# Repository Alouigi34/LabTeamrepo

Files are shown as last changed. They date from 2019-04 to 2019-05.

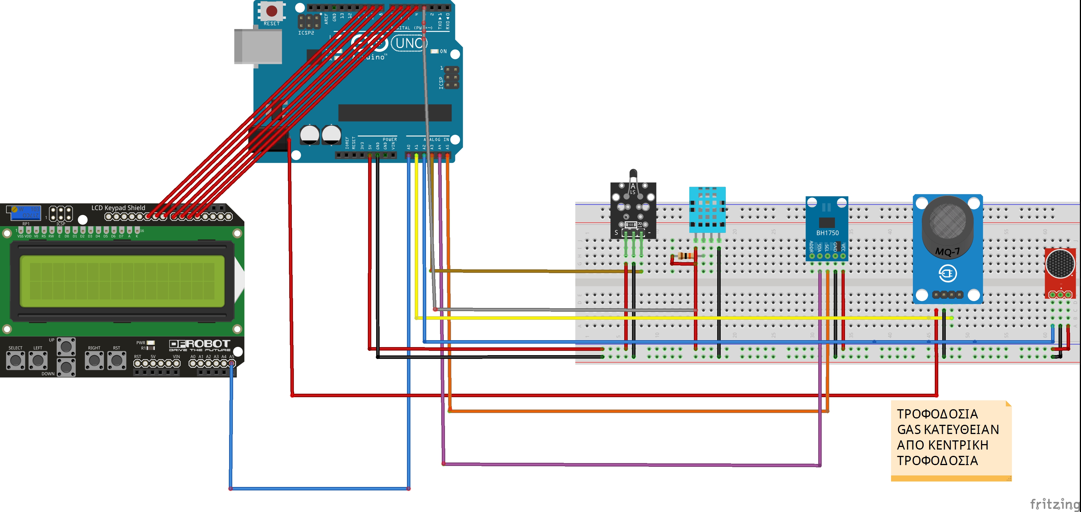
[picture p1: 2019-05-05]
Blueprints/Class_Quality_KYKLOMA_fritzing.jpg

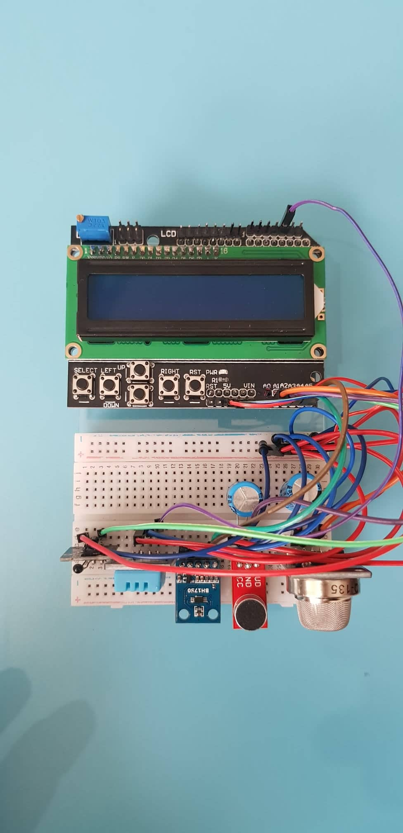
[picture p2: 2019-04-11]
Blueprints/εικονα.jpg

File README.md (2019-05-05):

# LabTeamrepo
Project for arduino competition

Αναλυτική περιγραφή ιδέας 

Η κατασκευή μας έχει σκοπό να μετρήσει την ποιότητα της ζωής μας στην σχολική τάξη. Μετράμε λοιπόν και αξιολογούμε στατιστικά, την θερμοκρασία της τάξης, το θόρυβο των παιδιών, το φως που έχουμε, και την υγρασία του χώρου. Όλες οι μετρήσεις μας συγκρίνονται με τις ιδανικές συνθήκες (παράδειγμα θερμοκρασία 20 βαθμοί και φως 250 λουξ και θόρυβος 35 ντεσιμπέλ) σύμφωνα με τις προδιαγραφές των σχολείων. Ολες οι μετρήσεις συμμετέχουν στο να φτιάξουμε ένα τελικό βαθμό ποιότητας.Το arduino μας  μετρά με τους αισθητήρες, υπολογίζει τον βαθμό και τον δείχνει σε οθόνη μαζί με τις μετρήσεις μία μία.
Στόχος είναι να μπει ένα arduino σε κάθε αίθουσα του σχολείου και να κάνουμε διαγωνισμό για την καλύτερη τάξη. Αυτό θα γίνεται κάθε μέρα και η καλύτερη τάξη στο τέλος του μήνα θα έχει ένα βραβείο από το σχολείο ή από το σύλλογο γονέων του σχολείου.

Χρειαστήκαμε τα παρακάτω υλικά
- 1 arduino UNO
- από έναν αισθητήρα: θερμοκρασίας, ήχου, φωτός, υγρασίας με τις αντιστάσεις τους
- 1 οθόνη 16x2 
- 1 RGB LED
- 1 breadboard και τα καλώδια για να τα ενώσουμε όλα μαζί 

Το συνολικό κόστος της τελικής κατασκευής,είναι περίπου 30 ευρώ

Περιηγηθείτε: 

Στο φάκελο Docs είναι τα αρχεία odt 

Στο φακελο code οι κώδικες

και στον φάκελο Blueprints είναι οι εικόνες και το κύκλωμα που σχεδιάσαμε στο fritzing!

Ο σύνδεσμος μας στο robotics.ellak:

https://robotics.ellak.gr/robotics_participant/metrisi-sinthikon-zois/

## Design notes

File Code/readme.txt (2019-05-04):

Οδηγίες για το arduino IDE
Τοποθετήστε όλα τα αρχεία στον ίδιο φάκελο και ονομάστε τον SCHOOL.
Το main αρχείο είναι το SCHOOL.ino
Να συμπεριλάβετε τις βιβλιοθήκες που βρίσκονται στον φάκελο

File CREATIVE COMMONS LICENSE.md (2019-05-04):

Όλο το υλικό η τεκμηρίωση, ο κώδικας,οι φωτογραφίες μας και όλο το περιεχόμενο του παρόντος site δημιουργήθηκε με open source software: Libre Office, Arduino, Frizzing και το διανέμουμε με άδεια χρήσης Creative Commons CC BY

Creative Commons Attribution-ShareAlike 4.0 International Public License

By exercising the Licensed Rights (defined below), You accept and agree to be bound by the terms and conditions of this Creative Commons Attribution-ShareAlike 4.0 International Public License ("Public License"). To the extent this Public License may be interpreted as a contract, You are granted the Licensed Rights in consideration of Your acceptance of these terms and conditions, and the Licensor grants You such rights in consideration of benefits the Licensor receives from making the Licensed Material available under these terms and conditions.

Section 1 – Definitions.
a.Adapted Material means material subject to Copyright and Similar Rights that is derived from or based upon the Licensed Material and in which the Licensed Material is translated, altered, arranged, transformed, or otherwise modified in a manner requiring permission under the Copyright and Similar Rights held by the Licensor. For purposes of this Public License, where the Licensed Material is a musical work, performance, or sound recording, Adapted Material is always produced where the Licensed Material is synched in timed relation with a moving image.
b.Adapter's License means the license You apply to Your Copyright and Similar Rights in Your contributions to Adapted Material in accordance with the terms and conditions of this Public License.
c.BY-SA Compatible License means a license listed at  creativecommons.org/compatiblelicenses, approved by Creative Commons as essentially the equivalent of this Public License.
d.Copyright and Similar Rights means copyright and/or similar rights closely related to copyright including, without limitation, performance, broadcast, sound recording, and Sui Generis Database Rights, without regard to how the rights are labeled or categorized. For purposes of this Public License, the rights specified in Section 2(b)(1)-(2) are not Copyright and Similar Rights.
e.Effective Technological Measures means those measures that, in the absence of proper authority, may not be circumvented under laws fulfilling obligations under Article 11 of the WIPO Copyright Treaty adopted on December 20, 1996, and/or similar international agreements.
f.Exceptions and Limitations means fair use, fair dealing, and/or any other exception or limitation to Copyright and Similar Rights that applies to Your use of the Licensed Material.
g.License Elements means the license attributes listed in the name of a Creative Commons Public License. The License Elements of this Public License are Attribution and ShareAlike.
h.Licensed Material means the artistic or literary work, database, or other material to which the Licensor applied this Public License.
i.Licensed Rights means the rights granted to You subject to the terms and conditions of this Public License, which are limited to all Copyright and Similar Rights that apply to Your use of the Licensed Material and that the Licensor has authority to license.
j.Licensor means the individual(s) or entity(ies) granting rights under this Public License.
k.Share means to provide material to the public by any means or process that requires permission under the Licensed Rights, such as reproduction, public display, public performance, distribution, dissemination, communication, or importation, and to make material available to the public including in ways that members of the public may access the material from a place and at a time individually chosen by them.
l.Sui Generis Database Rights means rights other than copyright resulting from Directive 96/9/EC of the European Parliament and of the Council of 11 March 1996 on the legal protection of databases, as amended and/or succeeded, as well as other essentially equivalent rights anywhere in the world.
m.You means the individual or entity exercising the Licensed Rights under this Public License. Your has a corresponding meaning.

Section 2 – Scope.
a.License grant. 1.Subject to the terms and conditions of this Public License, the Licensor hereby grants You a worldwide, royalty-free, non-sublicensable, non-exclusive, irrevocable license to exercise the Licensed Rights in the Licensed Material to: A.reproduce and Share the Licensed Material, in whole or in part; and
B.produce, reproduce, and Share Adapted Material.

2.Exceptions and Limitations. For the avoidance of doubt, where Exceptions and Limitations apply to Your use, this Public License does not apply, and You do not need to comply with its terms and conditions.
3.Term. The term of this Public License is specified in Section 6(a).
4.Media and formats; technical modifications allowed. The Licensor authorizes You to exercise the Licensed Rights in all media and formats whether now known or hereafter created, and to make technical modifications necessary to do so. The Licensor waives and/or agrees not to assert any right or authority to forbid You from making technical modifications necessary to exercise the Licensed Rights, including technical modifications necessary to circumvent Effective Technological Measures. For purposes of this Public License, simply making modifications authorized by this Section 2(a)(4) never produces Adapted Material.
5.Downstream recipients. 
A.Offer from the Licensor – Licensed Material. Every recipient of the Licensed Material automatically receives an offer from the Licensor to exercise the Licensed Rights under the terms and conditions of this Public License.
B.Additional offer from the Licensor – Adapted Material. Every recipient of Adapted Material from You automatically receives an offer from the Licensor to exercise the Licensed Rights in the Adapted Material under the conditions of the Adapter’s License You apply.
C.No downstream restrictions. You may not offer or impose any additional or different terms or conditions on, or apply any Effective Technological Measures to, the Licensed Material if doing so restricts exercise of the Licensed Rights by any recipient of the Licensed Material.

6.No endorsement. Nothing in this Public License constitutes or may be construed as permission to assert or imply that You are, or that Your use of the Licensed Material is, connected with, or sponsored, endorsed, or granted official status by, the Licensor or others designated to receive attribution as provided in Section 3(a)(1)(A)(i).

b.Other rights.
1.Moral rights, such as the right of integrity, are not licensed under this Public License, nor are publicity, privacy, and/or other similar personality rights; however, to the extent possible, the Licensor waives and/or agrees not to assert any such rights held by the Licensor to the limited extent necessary to allow You to exercise the Licensed Rights, but not otherwise.
2.Patent and trademark rights are not licensed under this Public License.
3.To the extent possible, the Licensor waives any right to collect royalties from You for the exercise of the Licensed Rights, whether directly or through a collecting society under any voluntary or waivable statutory or compulsory licensing scheme. In all other cases the Licensor expressly reserves any right to collect such royalties.

Section 3 – License Conditions.

Your exercise of the Licensed Rights is expressly made subject to the following conditions.

a.Attribution.

1.If You Share the Licensed Material (including in modified form), You must:
A.retain the following if it is supplied by the Licensor with the Licensed Material: i.identification of the creator(s) of the Licensed Material and any others designated to receive attribution, in any reasonable manner requested by the Licensor (including by pseudonym if designated);
ii.a copyright notice;
iii.a notice that refers to this Public License; 
iv.a notice that refers to the disclaimer of warranties;
v.a URI or hyperlink to the Licensed Material to the extent reasonably practicable;

B.indicate if You modified the Licensed Material and retain an indication of any previous modifications; and
C.indicate the Licensed Material is licensed under this Public License, and include the text of, or the URI or hyperlink to, this Public License.

2.You may satisfy the conditions in Section 3(a)(1) in any reasonable manner based on the medium, means, and context in which You Share the Licensed Material. For example, it may be reasonable to satisfy the conditions by providing a URI or hyperlink to a resource that includes the required information.
3.If requested by the Licensor, You must remove any of the information required by Section 3(a)(1)(A) to the extent reasonably practicable.

b.ShareAlike. 
In addition to the conditions in Section 3(a), if You Share Adapted Material You produce, the following conditions also apply.
1.The Adapter’s License You apply must be a Creative Commons license with the same License Elements, this version or later, or a BY-SA Compatible License.
2.You must include the text of, or the URI or hyperlink to, the Adapter's License You apply. You may satisfy this condition in any reasonable manner based on the medium, means, and context in which You Share Adapted Material.
3.You may not offer or impose any additional or different terms or conditions on, or apply any Effective Technological Measures to, Adapted Material that restrict exercise of the rights granted under the Adapter's License You apply.

Section 4 – Sui Generis Database Rights.

Where the Licensed Rights include Sui Generis Database Rights that apply to Your use of the Licensed Material:
a.for the avoidance of doubt, Section 2(a)(1) grants You the right to extract, reuse, reproduce, and Share all or a substantial portion of the contents of the database;
b.if You include all or a substantial portion of the database contents in a database in which You have Sui Generis Database Rights, then the database in which You have Sui Generis Database Rights (but not its individual contents) is Adapted Material, including for purposes of Section 3(b); and
c.You must comply with the conditions in Section 3(a) if You Share all or a substantial portion of the contents of the database.
For the avoidance of doubt, this Section 4 supplements and does not replace Your obligations under this Public License where the Licensed Rights include other Copyright and Similar Rights. 
Section 5 – Disclaimer of Warranties and Limitation of Liability.
a.Unless otherwise separately undertaken by the Licensor, to the extent possible, the Licensor offers the Licensed Material as-is and as-available, and makes no representations or warranties of any kind concerning the Licensed Material, whether express, implied, statutory, or other. This includes, without limitation, warranties of title, merchantability, fitness for a particular purpose, non-infringement, absence of latent or other defects, accuracy, or the presence or absence of errors, whether or not known or discoverable. Where disclaimers of warranties are not allowed in full or in part, this disclaimer may not apply to You.
b.To the extent possible, in no event will the Licensor be liable to You on any legal theory (including, without limitation, negligence) or otherwise for any direct, special, indirect, incidental, consequential, punitive, exemplary, or other losses, costs, expenses, or damages arising out of this Public License or use of the Licensed Material, even if the Licensor has been advised of the possibility of such losses, costs, expenses, or damages. Where a limitation of liability is not allowed in full or in part, this limitation may not apply to You.
c.The disclaimer of warranties and limitation of liability provided above shall be interpreted in a manner that, to the extent possible, most closely approximates an absolute disclaimer and waiver of all liability.

Section 6 – Term and Termination.
a.This Public License applies for the term of the Copyright and Similar Rights licensed here. However, if You fail to comply with this Public License, then Your rights under this Public License terminate automatically.

b.Where Your right to use the Licensed Material has terminated under Section 6(a), it reinstates:
1.automatically as of the date the violation is cured, provided it is cured within 30 days of Your discovery of the violation; or
2.upon express reinstatement by the Licensor.
For the avoidance of doubt, this Section 6(b) does not affect any right the Licensor may have to seek remedies for Your violations of this Public License.
c.For the avoidance of doubt, the Licensor may also offer the Licensed Material under separate terms or conditions or stop distributing the Licensed Material at any time; however, doing so will not terminate this Public License.
d.Sections 1, 5, 6, 7, and 8 survive termination of this Public License.

Section 7 – Other Terms and Conditions.
a.The Licensor shall not be bound by any additional or different terms or conditions communicated by You unless expressly agreed.
b.Any arrangements, understandings, or agreements regarding the Licensed Material not stated herein are separate from and independent of the terms and conditions of this Public License.

Section 8 – Interpretation.
a.For the avoidance of doubt, this Public License does not, and shall not be interpreted to, reduce, limit, restrict, or impose conditions on any use of the Licensed Material that could lawfully be made without permission under this Public License.
b.To the extent possible, if any provision of this Public License is deemed unenforceable, it shall be automatically reformed to the minimum extent necessary to make it enforceable. If the provision cannot be reformed, it shall be severed from this Public License without affecting the enforceability of the remaining terms and conditions.
c.No term or condition of this Public License will be waived and no failure to comply consented to unless expressly agreed to by the Licensor.
d.Nothing in this Public License constitutes or may be interpreted as a limitation upon, or waiver of, any privileges and immunities that apply to the Licensor or You, including from the legal processes of any jurisdiction or authority.

Creative Commons is not a party to its public licenses. Notwithstanding, Creative Commons may elect to apply one of its public licenses to material it publishes and in those instances will be considered the “Licensor.” The text of the Creative Commons public licenses is dedicated to the public domain under the CC0 Public Domain Dedication. Except for the limited purpose of indicating that material is shared under a Creative Commons public license or as otherwise permitted by the Creative Commons policies published at creativecommons.org/policies, Creative Commons does not authorize the use of the trademark “Creative Commons” or any other trademark or logo of Creative Commons without its prior written consent including, without limitation, in connection with any unauthorized modifications to any of its public licenses or any other arrangements, understandings, or agreements concerning use of licensed material. For the avoidance of doubt, this paragraph does not form part of the public licenses.

 Creative Commons may be contacted at creativecommons.org.

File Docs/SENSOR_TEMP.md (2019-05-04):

Ky-013 (Analog Temperature Sensor)

1.1Περιληπτική εισαγωγή:
Σκοπός του Analog Temperature Sensor (Analog Temp) είναι να υπολογίζει με ακρίβεια την θερμοκρασία μίας σχολικής τάξης, χρησιμοποιώντας μετρήσεις. Αυτές τις μετρήσεις στη συνέχεια με τη βοήθεια μαθηματικών πράξεων τις μετατρέπουμε στην τελική τους μορφή (θερμοκρασία).

1.2Βουτιά στα καλώδια:
Ο Analog Temp αποτελείται από δύο αντιστάσεις, μια μεταβλητή και μια σταθερή αντίσταση και λειτουργεί με την ίδια νοοτροπία μίας μεταβλητής αντίστασης.  Όσο η θερμοκρασία του δωματίου αυξάνεται, τόσο μειώνεται η τάση η οποία μεταφέρεται από τον αισθητήρα στον εγκέφαλο (arduino) . Έτσι, οι μετρήσεις που λαμβάνει το Arduino σε συνδυασμό με μια μικρή σειρά μαθηματικών πράξεων, μας επιτρέπουν να υπολογίσουμε την θερμοκρασία ενός χώρου 25 περίπου τετραγωνικών μέτρων.      

(συνδεσμολογία-εικόνα στο αντίστοιχο odt)

1.3 Η τελική τιμή:
Καθώς η θερμοκρασία η οποία μας δίνεται από τον αισθητήρα είναι σε Fahrenheit(F), είναι απαραίτητη μια μετατροπή, έτσι ώστε οι τιμές που λαμβάνουμε να είναι σε Celsius(C).
Στη συνέχεια με ένα πρόγραμμα optimization δικής μας κατασκευής, δημιουργούμε ένα τελικό σκορ, το οποίο μαζί με τις επιδόσεις των άλλων αισθητήρων μας δίνουν την τελική βαθμολογία!
Στον κώδικα φαίνονται περισσότερα με σχόλια και παρατηρήσεις.

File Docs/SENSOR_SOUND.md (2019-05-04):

SOUND SENSOR

Προκειμένου να καταλάβουμε το επίπεδο του θορύβου που υπάρχει μέσα σε μία τάξη χρησιμοποιούμε τον sound sensor. Αλλά πώς μπορούμε να μετρήσουμε το ήχο με το Arduino; Αυτό για να το εξηγήσουμε πρέπει πρώτα να δούμε την έξοδο του αισθητήρα και το επιτυγχάνουμε μέσω των  παρακάτω γραφημάτων.
(δείτε odt)
Καταρχάς ένα απλό ηχείο για να δημιουργήσει ήχο ταλαντώνει μια λεπτή πλαστική μεμβράνη η οποία από τις πολλές και συνεχόμενες ταλαντώσεις παράγει ήχο. Αυτή η ταλάντωση παρουσιάζεται ως γράφημα που μας δείχνει την ένταση του ήχου σε συνάρτηση με τον χρόνο (κόκκινο χρώμα). Όταν υπάρχει ησυχία μέσα στην τάξη τότε η κόκκινη γραμμή θα έχει πολύ μικρή διαφορά με την κίτρινη, η οποία εκφράζει την απόλυτη ησυχία (500).
(δείτε odt)
	Στο πρόγραμμα για να καταλάβουμε την μέση ένταση, αφαιρούμε σε κάθε δείγμα που παίρνουμε, την απόσταση του δείγματος από την αμετάβλητη τιμή για να βρούμε την διαφορά. Μετά από 100 μετρήσεις αθροίζουμε τις αποστάσεις  και τις διαιρούμε με το σύνολο των μετρήσεων. Έτσι βρίσκουμε τον μέσο όρο των αποστάσεων.
	Όπως βλέπουμε στο δεύτερο σχήμα επειδή σε αυτό υπάρχει μικρή απόσταση των σημείων από την αμετάβλητη τιμή (την κίτρινη γραμμή)  μέσα στην τάξη υπάρχει ησυχία, άρα συμπεραίνουμε ότι ο θόρυβος μέσα στην τάξη είναι ιδανικός.
	Η ένταση του ήχου μέσα στην τάξη μπορεί να μεταβληθεί πολύ γρήγορα (από ένα φτέρνισμα μέχρι και μια βροντή που μπορεί να ακουστεί από έξω από την τάξη). Για αυτό και εμείς παίρνουμε πολύ περισσότερες τιμές από τον sound sensor σε σχέση με τους υπολοίπους αισθητήρες που χρησιμοποιούμε. Για την ακρίβεια παίρνουμε 100 τιμές ανά 10 δευτερόλεπτα στον sound sensor ενώ στους υπόλοιπους sensors παίρνουμε 1 τιμή ανά 10 δευτερόλεπτα, γιατί οι άλλες τιμές οι οποίες μετράμε μεταβάλλονται πολύ πιο δύσκολα σε σχέση με τον ήχο μέσα σε μια τάξη.
Στον κώδικα έχουμε αναλυτικά και με  σχόλια τι κάνουμε.

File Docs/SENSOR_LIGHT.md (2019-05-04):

ΑΙΣΘΗΤΗΡΑΣ LIGHT
ΕΙΣΑΓΩΓΗ-ΠΕΡΙΛΗΨΗ

Η τάξη πρέπει να έχει 250 lux. O σκοπός του light sensor είναι να ξέρουμε τι φωτεινότητα έχει η τάξη
και ανάλογα με το φως να βάζουμε μία βαθμολογία για την ποιότητα του φωτός όλης της ημέρας.
 
ΑΞΙΟΠΟΙΗΣΗ ΜΕΤΡΟΥΜΕΝΗΣ ΤΙΜΗΣ ΑΠΟ ΤΟ ARDUINO

Διαβάζοντας τις τιμές από τον αισθητήρα παρατηρήσαμε ότι οι μετρούμενες τιμές δεν ήταν σε lux. Τα κινητά μας είχαν αισθητήρες φωτός και τα χρησιμοποιήσαμε ως όργανα μέτρησης. Χρησιμοποιώντας ένα φακό φωτίζαμε συγχρόνως και τους δύο αισθητήρες (του κινητού και τον δικό μας). Ο αισθητήρας του κινητού ήταν η αναφορά μας. Τους φωτίσαμε από πολλά διαφορετικά ύψη και με το LibreOffice Calc φτιάξαμε έναν πίνακα δύο στηλών. Η πρώτη στήλη ήταν οι μετρήσεις του κινητού ενώ η δεύτερη στήλη ήταν οι μετρήσεις του αισθητήρα μας.

Βρήκαμε έναν τύπο που συνδέει τις μετρήσεις του κινητού με τις μετρήσεις του αισθητήρα. Και τον χρησιμοποιήσαμε μέσα στον κώδικα για να μετατρέπουμε τις τιμές που διαβάζουμε από το arduino σε lux.

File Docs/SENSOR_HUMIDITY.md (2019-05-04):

ΑΙΣΘΗΤΗΡΑΣ υγρασίας

Χρησιμοποιούμε τον αισθητήρα θερμοκρασίας και υγρασίας  DHT11  γιατί ήταν ο πιο φθηνός και επειδή καθιστά πραγματικά εύκολη την προσθήκη δεδομένων υγρασίας και θερμοκρασίας.

ΑΞΙΟΠΟΙΗΣΗ ΜΕΤΡΟΥΜΕΝΗΣ ΤΙΜΗΣ ΑΠΟ ΤΟ ARDUINO
Η κατάλληλη υγρασία είναι περίπου 50% όλες τις εποχές. Τα όρια που χρησιμοποιήσαμε είναι τα εξής: {0, 15, 55,80, 100}

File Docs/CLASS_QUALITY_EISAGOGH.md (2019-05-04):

CQM0419 – Class Quality Monitor  - Απρίλιος 2019

Δημιουργία συσκευής που μετρά την ποιότητα της τάξης

Η καθημερινή μας ζωή στην σχολική τάξη μπορεί να βελτιωθεί αν οι περιβαλλοντικές συνθήκες είναι όσο δυνατόν καλύτερες. Όταν κάτι δεν μας αρέσει πρέπει να βρούμε εύκολα τι είναι αυτό που μας προκαλεί δυσφορία.  

Αποφασίσαμε να φτιάξουμε μία κατασκευή που θα μπορεί να μετρά την ποιότητα ζωής στην τάξη με σκοπό να την βελτιώσει. Βασικοί παράγοντες που επηρεάζουν τη ζωή στην τάξη, είναι οι συνθήκες θερμοκρασίας, υγρασίας, θορύβου, φωτός και ποιότητας αέρα. Η κατασκευή μας είναι οι αισθητήρες αυτοί όλοι μαζί σε ένα arduino, μία lcd μικρή οθόνη που θα δείχνει τα αναλυτικά αποτελέσματα και ένα led που θα ανάβει πράσινο, κίτρινο ή κόκκινο αν η τάξη συνολικά είναι άριστη, μέτρια ή κακή.

Η ομάδα μας έχει μαθητές από Πέμπτη Δημοτικού μέχρι Τρίτη Γυμνασίου και προκειμένου να επιτύχουμε τον στόχο μας, δημιουργήσαμε μία υπο-ομάδα για κάθε αισθητήρα χωριστά και μία ομάδα για το τελικό integration. Αφότου κάθε ομάδα ολοκλήρωσε τη δουλειά της, χωριστήκαμε εκ νέου σε νέες ομάδες προκειμένου σχεδιάσουμε το κύκλωμα σε fritzing, να γράψουμε τα documents, να κάνουμε αποσφαλμάτωση στους κώδικες και να βελτιώσουμε τον κώδικα και το hardware.
Η όλη φιλοσοφία της κατασκευής είναι να παίρνουμε μετρήσεις από κάθε αισθητήρα και ανά τακτά διαστήματα να τις αξιολογούμε καθεμία και όλες μαζί.

Αντιμετωπίσαμε πολλά προβλήματα. Προβλήματα συνεννόησης, χρόνου, οργάνωσης συναντήσεων, προβλήματα με το software αλλά και το hardware. Οι κώδικες χρήσης αισθητήρων, που βρήκαμε από το internet, δε δούλευαν πάντα σωστά και έπρεπε να τους κάνουμε κάποιες μετατροπές. Έπειτα, μας δυσκόλεψε πολύ η ενοποίηση των επιμέρους προγραμμάτων σε ένα τελικό. Στο hardware, έπρεπε να είμαστε πολύ προσεκτικοί με την θέση των αισθητήρων και επιλογή των pins γιατί είχαμε πολλούς αισθητήρες και μία lcd οθόνη που έπιαναν πολλά pins. Ήταν πολύ σημαντική η σωστή διάταξη των αισθητήρων πάνω στο breadboard διότι για παράδειγμα αν ο gas sensor που ζεσταινότανε πολύ, κατά τη διάρκεια της λειτουργίας του, ήταν δίπλα στον temperature sensor το αποτέλεσμα θα ήταν λανθασμένο. Θέλει πολύ προσοχή η σωστή χρήση της συσκευής. Για παράδειγμα δεν πρέπει να σκύβουμε από πάνω γιατί ο light sensor θα βγάλει λάθος μετρήσεις. Να επισημάνουμε μια ιδιαιτερότητα που είχε ο gas sensor, ότι η τροφοδοσία του δεν έπρεπε να γίνεται μέσο της τροφοδοσίας του arduino, αλλά μέσο της USB τροφοδοσίας. Διαφορετικά, επειδή ο gas sensor καταναλώνει πολύ ρεύμα, η lcd οθόνη τρεμοπαίζει και γενικά όλο το κύκλωμα είναι ασταθές.

Χαιρόμαστε γιατί μάθαμε πολλά πράγματα. Είδαμε πόσο ωραίο είναι να δουλεύεις σε ομάδες, με όλες τις δυσκολίες μας. Μάθαμε με τη βοήθεια του δασκάλου μας να φτιάχνουμε καλύτερο και παραμετρικό κώδικα (ειδικά με το integration) και πόσο πραγματικά βολεύει να σχεδιάζουμε τα πάντα στο χαρτί (κύκλωμα και κώδικα) πριν τα υλοποιήσουμε.
Τώρα έχουμε μια πλήρη κατασκευή που σε 5 λεπτά αλλάζουμε ότι θέλουμε (καλύτερους αισθητήρες, παραμέτρους ελέγχους ποιότητας μετρήσεων) και θα θέλαμε να την δούμε ζωντανά  να δουλεύει σε πραγματική λειτουργία σε κάθε τάξη στα σχολεία μας.

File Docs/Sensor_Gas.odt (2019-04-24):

Air Quality

1.1

Ο Air Quality MQ-135 είναι ένας αισθητήρας που μετράει την ποιότητα του αέρα. Για παράδειγμα μετράει το CO2 (το διοξείδιο του άνθρακα), την αλκοόλη ,τον καπνό , το NH3(αμμωνία) κτλ. Χρησιμοποιείται ως δείκτης ποιότητας του αέρα AQI (Air Quality index) . Για το πόσο μολυσμένος είναι ο αέρας σήμερα ή πόσο μολυσμένος προβλέπεται να γίνει. Καθώς αυξάνεται το AQI (Air Quality index), μεγάλο ποσοστό του πληθυσμού είναι πιθανό να εμφανίσει όλο και πιο σοβαρές επιπτώσεις στην υγεία του. Οι διάφορες χώρες έχουν τους δικούς τους δείκτες ποιότητας του αέρα, οι οποίοι αντιστοιχούν σε διαφορετικά εθνικά πρότυπα. Μερικά από αυτά είναι ο Δείκτης Υγείας Ποιότητας Αέρα (Καναδάς), ο Δείκτης Αέριας Ρύπανσης (Μαλαισία) και ο Δείκτης Πρότυπων Ρύπων (Σιγκαπούρη). Η ποιότητα του αέρα της τάξης είναι πολύ σημαντική για να μην αρρωσταίνουν ευκολά τα παιδιά και για να μπορούν να παρακολουθήσουν καλύτερα στο μάθημα .Συγκεκριμένα οι τιμές του CO2(διοξείδιού του άνθρακα ) πρέπει να είναι <1000ppm σύμφωνα με τα διεθνή στάνταρ.

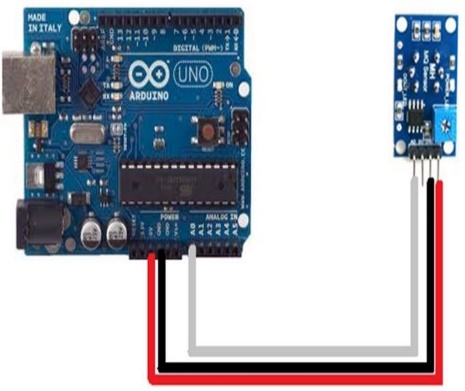
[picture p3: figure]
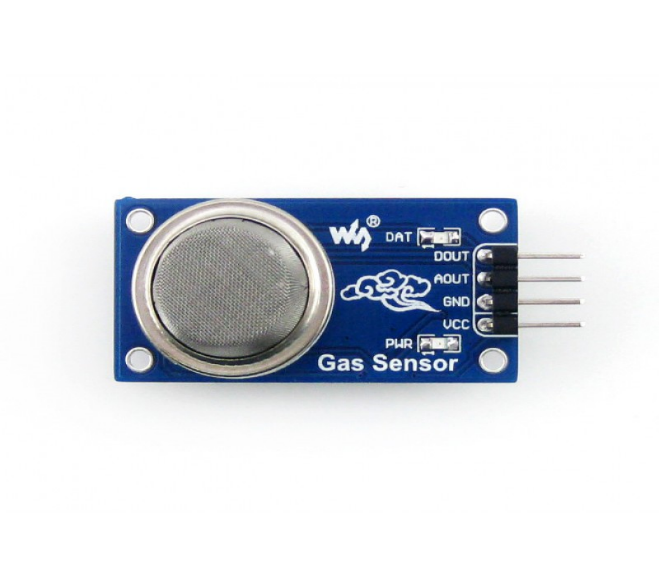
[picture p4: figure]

1.2

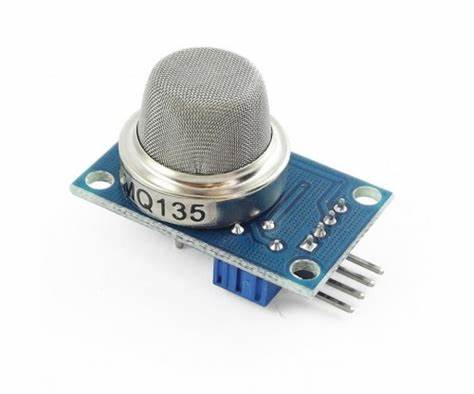
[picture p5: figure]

Ι) στην εικόνα αυτή βλέπουμε τον sensor MQ-135 VCC=5v

GND=GND

ADUT=8

DDUT=9

1.3

Οι αποδεκτές τιμές είναι κάτω από 1000ppm . Ο sensor MQ-135 δεν χρειάζεται μετατροπή γιατί μετράει σε ppm .

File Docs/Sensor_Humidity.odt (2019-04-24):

# 1.ΑΙΣΘΗΤΗΡΑΣ υγρασίας

## 1.1.ΕΙΣΑΓΩΓΗ-ΠΕΡΙΛΗΨΗ

Σε αυτή την ενότητα θα επικεντρωθούμε στον αισθητήρα υγρασίας.

Χρησιμοποιούμε τον αισθητήρα θερμοκρασίας και υγρασίας DHT11 γιατί ήταν ο πιο φθηνός και επειδή καθιστά πραγματικά εύκολη την προσθήκη δεδομένων υγρασίας και θερμοκρασίας.
1.2.Ο ΑΙΣΘΗΤΗΡΑΣ ΜΑΣ

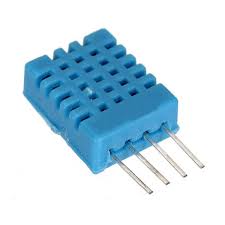
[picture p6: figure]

Εικόνα 1 :O αισθητήρας DHT_11

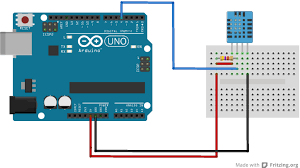
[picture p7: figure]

Εικόνα 2:H συνδεσμολογία του DHT_11 με το arduino.

## 1.3.ΑΞΙΟΠΟΙΗΣΗ ΜΕΤΡΟΥΜΕΝΗΣ ΤΙΜΗΣ ΑΠΟ ΤΟ ARDUINO

Η κατάλληλη υγρασία είναι περίπου 50% όλες τις εποχές. Τα όρια που χρησιμοποιήσαμε αρχικά είναι τα εξής: {0, 15, 55,80, 100}

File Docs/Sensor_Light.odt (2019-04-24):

# 1.ΑΙΣΘΗΤΗΡΑΣ LIGHT

## 1.1.ΕΙΣΑΓΩΓΗ-ΠΕΡΙΛΗΨΗ

Η τάξη πρέπει να έχει 250 lux. O σκοπός του light sensor είναι να ξέρουμε τι φωτεινότητα έχει η τάξη

και ανάλογα με το φως να βάζουμε μία βαθμολογία για την ποιότητα του φωτός όλης της ημέρας.

## 1.2.Ο ΑΙΣΘΗΤΗΡΑΣ ΜΑΣ

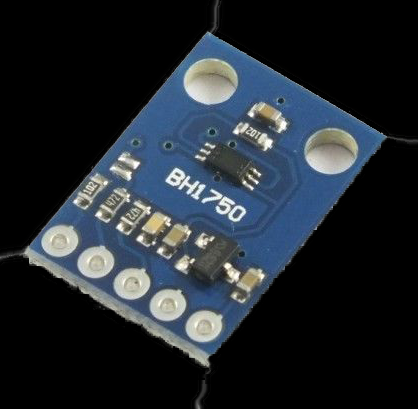
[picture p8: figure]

Εικόνα 1: Εικόνα του αισθητήρα

## 1.3.ΑΞΙΟΠΟΙΗΣΗ ΜΕΤΡΟΥΜΕΝΗΣ ΤΙΜΗΣ ΑΠΟ ΤΟ ARDUINO

Διαβάζοντας τις τιμές από τον αισθητήρα παρατηρήσαμε ότι οι μετρούμενες τιμές δεν ήταν σε lux. Τα κινητά μας είχαν αισθητήρες φωτός και τα χρησιμοποιήσαμε ως όργανα μέτρησης. Χρησιμοποιώντας ένα φακό φωτίζαμε συγχρόνως και τους δύο αισθητήρες (του κινητού και τον δικό μας). Ο αισθητήρας του κινητού ήταν η αναφορά μας. Τους φωτίσαμε από πολλά διαφορετικά ύψη και με το LibreOffice Calc φτιάξαμε έναν πίνακα δύο στηλών. Η πρώτη στήλη ήταν οι μετρήσεις του κινητού ενώ η δεύτερη στήλη ήταν οι μετρήσεις του αισθητήρα μας.

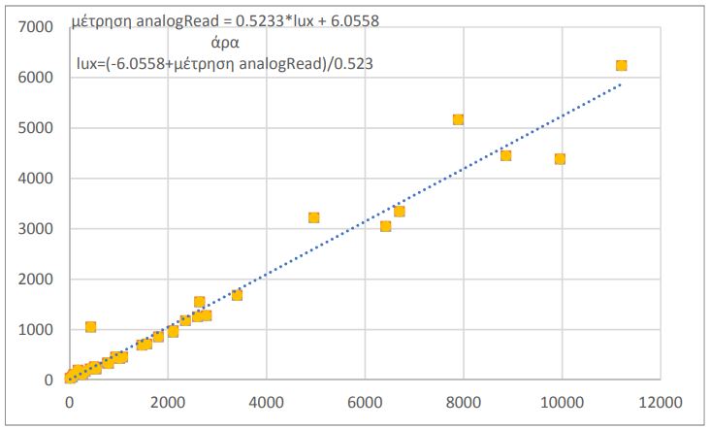
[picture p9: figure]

ΕΙΚΟΝΑ 1: Kάθετος άξονας: μετρήσεις κινητού. Oριζόντιος άξονας: Mετρήσεις arduino.

Βρήκαμε έναν τύπο που συνδέει τις μετρήσεις του κινητού με τις μετρήσεις του αισθητήρα. Και τον χρησιμοποιήσαμε μέσα στον κώδικα για να μετατρέπουμε τις τιμές που διαβάζουμε από το arduino σε lux.

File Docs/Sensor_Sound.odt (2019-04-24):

SOUND SENSOR

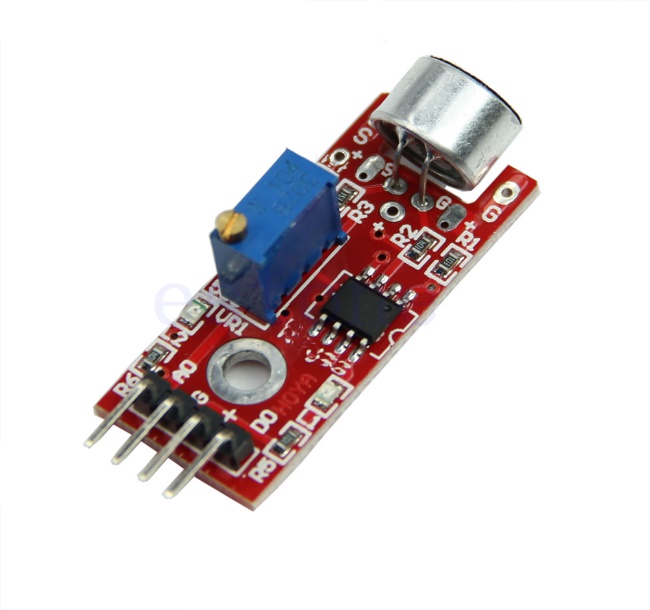
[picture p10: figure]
Εμφάνιση της εικόνας προέλευσης
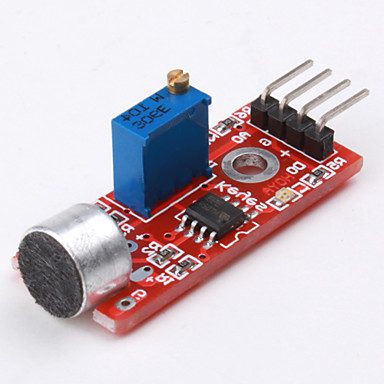
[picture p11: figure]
Εμφάνιση της εικόνας προέλευσης

Προκειμένου να καταλάβουμε το επίπεδο του θορύβου που υπάρχει μέσα σε μία τάξη χρησιμοποιούμε τον sound sensor. Αλλά πώς μπορούμε να μετρήσουμε το ήχο με το Arduino; Αυτό για να το εξηγήσουμε πρέπει πρώτα να δούμε την έξοδο του αισθητήρα και το επιτυγχάνουμε μέσω των παρακάτω γραφημάτων.

Εικόνα 1: Η έξοδος του αισθητήρα στην ησυχία (-->κίτρινη γραμμή: η απόλυτη ησυχία--> κόκινη γραμμή: έξοδος αισθητήρα )

Εικόνα 2: Η έξοδος του αισθητήρα στην φασαρία (-->κίτρινη γραμμή: η απόλυτη ησυχία--> κόκινη γραμμή: έξοδος αισθητήρα )

Καταρχάς ένα απλό ηχείο για να δημιουργήσει ήχο ταλαντώνει μια λεπτή πλαστική μεμβράνη η οποία από τις πολλές και συνεχόμενες ταλαντώσεις παράγει ήχο. Αυτή η ταλάντωση παρουσιάζεται ως γράφημα που μας δείχνει την ένταση του ήχου σε συνάρτηση με τον χρόνο (κόκκινο χρώμα). Όταν υπάρχει ησυχία μέσα στην τάξη τότε η κόκκινη γραμμή θα έχει πολύ μικρή διαφορά με την κίτρινη, η οποία εκφράζει την απόλυτη ησυχία (500).

Στο πρόγραμμα για να καταλάβουμε την μέση ένταση, αφαιρούμε σε κάθε δείγμα που παίρνουμε, την απόσταση του δείγματος από την αμετάβλητη τιμή για να βρούμε την διαφορά. Μετά από 100 μετρήσεις αθροίζουμε τις αποστάσεις και τις διαιρούμε με το σύνολο των μετρήσεων. Έτσι βρίσκουμε τον μέσο όρο των αποστάσεων.

Όπως βλέπουμε στο δεύτερο σχήμα επειδή σε αυτό υπάρχει μικρή απόσταση των σημείων από την αμετάβλητη τιμή (την κίτρινη γραμμή) μέσα στην τάξη υπάρχει ησυχία, άρα συμπεραίνουμε ότι ο θόρυβος μέσα στην τάξη είναι ιδανικός.

Η ένταση του ήχου μέσα στην τάξη μπορεί να μεταβληθεί πολύ γρήγορα (από ένα φτέρνισμα μέχρι και μια βροντή που μπορεί να ακουστεί από έξω από την τάξη). Για αυτό και εμείς παίρνουμε πολύ περισσότερες τιμές από τον sound sensor σε σχέση με τους υπολοίπους αισθητήρες που χρησιμοποιούμε. Για την ακρίβεια παίρνουμε 100 τιμές ανά 10 δευτερόλεπτα στον sound sensor ενώ στους υπόλοιπους sensors παίρνουμε 1 τιμή ανά 10 δευτερόλεπτα, γιατί οι άλλες τιμές οι οποίες μετράμε μεταβάλλονται πολύ πιο δύσκολα σε σχέση με τον ήχο μέσα σε μια τάξη.

Στον κώδικα έχουμε αναλυτικά και με σχόλια τι κάνουμε.

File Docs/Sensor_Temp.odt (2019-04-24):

Ky-013 (Analog Temperature Sensor)

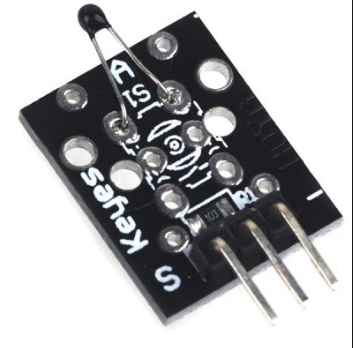
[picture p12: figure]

1.1Περιληπτική εισαγωγή:

Σκοπός του Analog Temperature Sensor (Analog Temp) είναι να υπολογίζει με ακρίβεια την θερμοκρασία μίας σχολικής τάξης, χρησιμοποιώντας μετρήσεις. Αυτές τις μετρήσεις στη συνέχεια με τη βοήθεια μαθηματικών πράξεων τις μετατρέπουμε στην τελική τους μορφή (θερμοκρασία).

1.2Βουτιά στα καλώδια:

Ο Analog Temp αποτελείται από δύο αντιστάσεις, μια μεταβλητή και μια σταθερή αντίσταση και λειτουργεί με την ίδια νοοτροπία μίας μεταβλητής αντίστασης. Όσο η θερμοκρασία του δωματίου αυξάνεται, τόσο μειώνεται η τάση η οποία μεταφέρεται από τον αισθητήρα στον εγκέφαλο (arduino) . Έτσι, οι μετρήσεις που λαμβάνει το Arduino σε συνδυασμό με μια μικρή σειρά μαθηματικών πράξεων, μας επιτρέπουν να υπολογίσουμε την θερμοκρασία ενός χώρου 25 περίπου τετραγωνικών μέτρων.

Η παρακάτω εικόνα απεικονίζει τη συνδεσμολογία του αισθητήρα

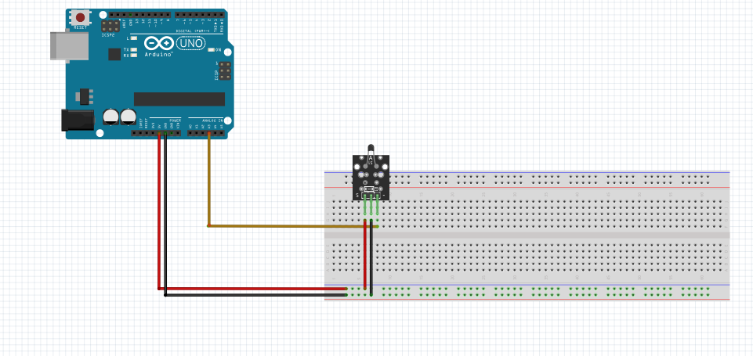
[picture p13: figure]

Το καφέ καλώδιο συνδέεται με το Pin A3 και με ένα “πόδι” του αισθητήρα, έτσι ώστε να μεταφέρονται οι μετρήσεις του.

Τα άλλα δυο καλώδια έχουν σχέση με την παροχή ενέργειας του (5 volt και γείωση).

1.3 Η τελική τιμή:

Καθώς η θερμοκρασία η οποία μας δίνεται από τον αισθητήρα είναι σε Fahrenheit(F), είναι απαραίτητη μια μετατροπή, έτσι ώστε οι τιμές που λαμβάνουμε να είναι σε Celsius(C).

Στη συνέχεια με ένα πρόγραμμα optimization δικής μας κατασκευής, δημιουργούμε ένα τελικό σκορ, το οποίο μαζί με τις επιδόσεις των άλλων αισθητήρων μας δίνουν την τελική βαθμολογία!

Στον κώδικα φαίνονται περισσότερα με σχόλια και παρατηρήσεις.

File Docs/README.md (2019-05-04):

Εδώ περιγράφουμε αναλυτικά τη κατασκευή μας.
Προτιμήστε τα odt αρχεία γιατί περιέχουν εικόνες και σχήματα που βοηθούν στην κατανόηση.

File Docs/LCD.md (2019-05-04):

LCD Screen

Στην οθόνη, ανάλογα με το κουμπί που πατάμε, εκτυπώνουμε τον πίνακα κατανομής που αντιστοιχεί στον αισθητήρα που επιλέγουμε. Επίσης, εκτυπώνουμε την τρέχουσα τιμή του αισθητήρα.

Παράδειγμα
2  33  180 100 0
TEMP 22 ΟΚ!

Ανά τακτά χρονικά διαστήματα (συνάρτηση millis() ) εκτυπώνουμε μαζί το αποτέλεσμα για κάθε έναν από τους αισθητήρες. Αν το αποτέλεσμα είναι green εκτυπώνει “ΟΚ!”, αν είναι red εκτυπώνει “BAD” ένω αν είναι yellow “MED”.  

Παράδειγμα
TemSndGasLigAirG
OK!OK!MEDMEDOK!Y

To G στο τέλος είναι η Global  βαθμολογία, Yellow εδώ γιατί έχουμε μόνο τρία πράσινα και  θέλουμε  τουλάχιστον τέσσερα πράσινα για να  είναι όλο πράσινο!

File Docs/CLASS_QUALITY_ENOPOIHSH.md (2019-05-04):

Integration Team

Η ομάδα μας είχε αναλάβει την ενοποίηση (integration) της κατασκευής μας. Δηλαδή, πήραμε τη δουλειά των υπόλοιπων ομάδων και την ενώσαμε δημιουργώντας την τελική κατασκευή που θα παρουσιάσουμε στον διαγωνισμό. Η δουλειά μας χωρίζεται σε δύο μέρη:

1.	Ενοποίηση των προγραμμάτων: Αφού οι υπόλοιπες ομάδες, που είχαν αναλάβει από έναν αισθητήρα η κάθε μία, τελείωσαν τη δουλειά τους και έκαναν κάθε αισθητήρα να δουλεύει αυτόνομα έδωσαν στην ομάδα μας τα προγράμματά τους και τα κυκλώματά τους. Εμείς τα πήραμε και τα ενώσαμε δημιουργώντας ένα μεγαλύτερο πρόγραμμα με διάφορα tabs, τα οποία περιέχουν τα προγράμματα των αισθητήρων χωριστά. Προσθέσαμε μερικά ακόμα tabs, ένα για την lcd, στην οποία θα φαίνονται τα αποτελέσματα των μετρήσεών μας, ένα κεντρικό tab, στο οποίο καλούνται τα προγράμματα των υπόλοιπων tab και γίνονται οι υπολογισμοί, και ένα tab με global defines και μεταβλητές ώστε να έχουμε συγκεντρωμένες όλες τις παραμέτρους κάπου μαζί. Στη συνέχεια, αρχίσαμε να γράφουμε το τελικό πρόγραμμα, που θα έκανε και όλους τους υπολογισμούς για να βρούμε πια τάξη τελικά είναι η καλύτερη.

2.	Ενοποίηση της κατασκευής: Μόλις οι υπόλοιπες ομάδες τελείωσαν το hardware κομμάτι της δουλειάς τους, μας έδωσαν τη συνδεσμολογία τους για τους αισθητήρες (αρχείο fritzing) και τους  αισθητήρες. Αρχίσαμε με τη σύνδεση δύο αισθητήρων για δοκιμή και μετά συνεχίσαμε συνδέοντας τους υπόλοιπους αισθητήρες. Όταν συνδέσαμε όλους τους αισθητήρες, κάνοντας τις απαραίτητες αλλαγές στο πρόγραμμα, τους δοκιμάσαμε και διορθώσαμε τα λάθη μας.

Ο αλγόριθμος που αποφασίζει τη βαθμολογία

Είχαμε σκεφτεί στην αρχή να αποθηκεύουμε τις τιμές των μετρήσεων σε έναν πίνακα και να βγάζουμε τον μέσο όρο. Αυτή η προσέγγιση δεν ήταν εφικτή διότι
1) ο πίνακας θα έπρεπε να είναι πολύ μεγάλος.
2)Ακόμα κι αν μπορούσαμε να είχαμε χιλιάδες τιμές και να βγάζουμε τον μέσο όρο θα ήταν λάθος. Για να το εξηγήσουμε αυτό θα σας παρουσιάσουμε ένα παράδειγμα του αισθητήρα θερμοκρασίας.

Έστω ότι στην πρώτη περίπτωση είχαμε πάρει από μία τάξη τις εξής 10 μετρήσεις:
 17,  23, 17, 23, 17, 23, 17, 23, 17, 23 (oC) = Ο μέσος όρος θα ήταν 20 oC.
Ενώ στη δεύτερη περίπτωση είχαμε πάρει τις εξής 10 μετρήσεις:
 20, 20, 20, 20, 20, 20, 20, 20, 20, 20 (oC) =  Ο μέσος όρος προκύπτει πάλι 20 oC.
Δεν  είναι σωστός λοιπόν ο μέσος όρος γιατί δεν δείχνει το ανεβοκατέβασμα της πρώτης τάξης  και τελικά την δείχνει  ίδια  με τη δεύτερη ενώ δεν είναι.

Για να λύσουμε το παραπάνω πρόβλημα, σε κάθε αισθητήρα έχουμε έναν πίνακα κατανομής (distrib) πέντε θέσεων. Κάθε φορά που παίρνουμε μέτρηση από τον αισθητήρα αυξάνεται κατά ένα, η μία από τις πέντε θέσεις του αντίστοιχου πίνακα κατανομής. Επίσης για κάθε αισθητήρα έχουμε έναν πίνακα, τα στοιχεία του οποίου εκφράζουν τα όρια της κάθε ζώνης (limits). Υπάρχουν τρεις ζώνες: η green, η yellow και η red. Η green εκφράζει τις αποδεκτές μετρήσεις, η yellow τις μεσαίες και η red τις μη αποδεκτές. Η green είναι το μεσαίο στοιχείο του πίνακα (distrib[2]), η yellow είναι τα distrib[1] και distrib[3] ενώ η red τα distrib[0] και distrib[4].
Κάθε φορά που καλείται η συνάρτηση υπολογισμού της ποιότητας της τάξης, βρίσκουμε το ποσοστό των καλών, των μέτριων και των κακών μετρήσεων. Για να το κάνουμε αυτό αρχικά προσθέτουμε τα στοιχεία του πίνακα και αποθηκεύουμε το αποτέλεσμα στην μεταβλητή SUM. Έπειτα διαιρούμε τις καλές μετρήσεις (distrib[2]) με το SUM,διαιρούμε τις μέτριες μετρήσεις (distrib[1]+distrib[3]) με το SUM και τέλος τις κακές μετρήσεις (distrib[0]+distrib[4]) πάλι με το SUM.

Για παράδειγμα παίρνουμε 3% κακές μετρήσεις, 27% μέτριες μετρήσεις και 70% άριστες.  Τώρα έρχεται ένα άλλο πρόβλημα: Πως βαθμολογείται  αυτή η τάξη μας  μετά  από όλες αυτές  τις  μετρήσεις  μαζί;  Κακή, μέτρια ή άριστη;

Πρέπει να αποφασίσουμε εάν το ποσοστό των άριστων μετρήσεων είναι αρκετά υψηλό και το ποσοστό των κακών και των μέτριων μετρήσεων είναι αρκετά χαμηλό. Σκεφτήκαμε το  εξής. Αν πάνω από 5% είναι κακές μετρήσεις τότε το τελικό αποτέλεσμα είναι κακό. Δηλαδή αν σε μία ώρα ο θόρυβος είναι τεράστιος πάνω από τρία λεπτά, τότε όλη η ώρα βαθμολογείται κακή. Για  να βγει μέτρια πρέπει να  είναι 12 λεπτά  μέτρια, αλλιώς (δηλαδή πάνω από 45 λεπτά) βγαίνει άριστη.

Για να το φτιάξουμε σε κώδικα  συγκρίνουμε αρχικά το ποσοστό των κακών μετρήσεων με ένα ποσοστιαίο όριο που θέσαμε εμείς (5%). Έπειτα  συγκρίνουμε  το ποσοστό των μέτριων μετρήσεων με το 20%. Τέλος τις καλές μετρήσεις με το 75%. 

Όλα είναι παραμετρικά  στο πρόγραμμά μας και εύκολα αλλάζουμε  τα  ποσοστά πχ. αλλάζουμε το #define  RED_PCT 0.05 σε #define  RED_PCT 0.10 για να κάνουμε  να ανάβει κόκκινο αν έχουμε πάνω από 10% κακές  μετρήσεις.

Τέλος για  να βαθμολογήσουμε ΟΛΗ την τάξη, έχοντας 5 αισθητήρες κόκκινους,  κίτρινους ή πράσινους ο καθένας διαφορετικός  σκεφτήκαμε διάφορα, απλά  και πολύπλοκα,  και καταλήξαμε τελικά  στο εξής απλό:

Αν  δύο ή παραπάνω  είναι κόκκινοι, τότε όλη η τάξη είναι κόκκινη, αλλιώς
αν τέσσερις ή παραπάνω  είναι πράσινοι  τότε όλη η τάξη είναι πράσινη, αλλιώς
ολη η τάξη είναι κίτρινη. Αυτό είναι εύκολο να το θυμόμαστε, εύκολο να το αλλάξουμε και μοιάζει τελικά σωστότερο από όλα  τα άλλα που σκεφτήκαμε.

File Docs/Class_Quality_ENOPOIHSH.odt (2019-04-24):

Integration Team

Η ομάδα μας είχε αναλάβει την ενοποίηση (integration) της κατασκευής μας. Δηλαδή, πήραμε τη δουλειά των υπόλοιπων ομάδων και την ενώσαμε δημιουργώντας την τελική κατασκευή που θα παρουσιάσουμε στον διαγωνισμό. Η δουλειά μας χωρίζεται σε δύο μέρη:

1. Ενοποίηση των προγραμμάτων: Αφού οι υπόλοιπες ομάδες, που είχαν αναλάβει από έναν αισθητήρα η κάθε μία, τελείωσαν τη δουλειά τους και έκαναν κάθε αισθητήρα να δουλεύει αυτόνομα έδωσαν στην ομάδα μας τα προγράμματά τους και τα κυκλώματά τους. Εμείς τα πήραμε και τα ενώσαμε δημιουργώντας ένα μεγαλύτερο πρόγραμμα με διάφορα tabs, τα οποία περιέχουν τα προγράμματα των αισθητήρων χωριστά. Προσθέσαμε μερικά ακόμα tabs, ένα για την lcd, στην οποία θα φαίνονται τα αποτελέσματα των μετρήσεών μας, ένα κεντρικό tab, στο οποίο καλούνται τα προγράμματα των υπόλοιπων tab και γίνονται οι υπολογισμοί, και ένα tab με global defines και μεταβλητές ώστε να έχουμε συγκεντρωμένες όλες τις παραμέτρους κάπου μαζί. Στη συνέχεια, αρχίσαμε να γράφουμε το τελικό πρόγραμμα, που θα έκανε και όλους τους υπολογισμούς για να βρούμε πια τάξη τελικά είναι η καλύτερη.
2. Ενοποίηση της κατασκευής: Μόλις οι υπόλοιπες ομάδες τελείωσαν το hardware κομμάτι της δουλειάς τους, μας έδωσαν τη συνδεσμολογία τους για τους αισθητήρες (αρχείο fritzing) και τους αισθητήρες. Αρχίσαμε με τη σύνδεση δύο αισθητήρων για δοκιμή και μετά συνεχίσαμε συνδέοντας τους υπόλοιπους αισθητήρες. Όταν συνδέσαμε όλους τους αισθητήρες, κάνοντας τις απαραίτητες αλλαγές στο πρόγραμμα, τους δοκιμάσαμε και διορθώσαμε τα λάθη μας.

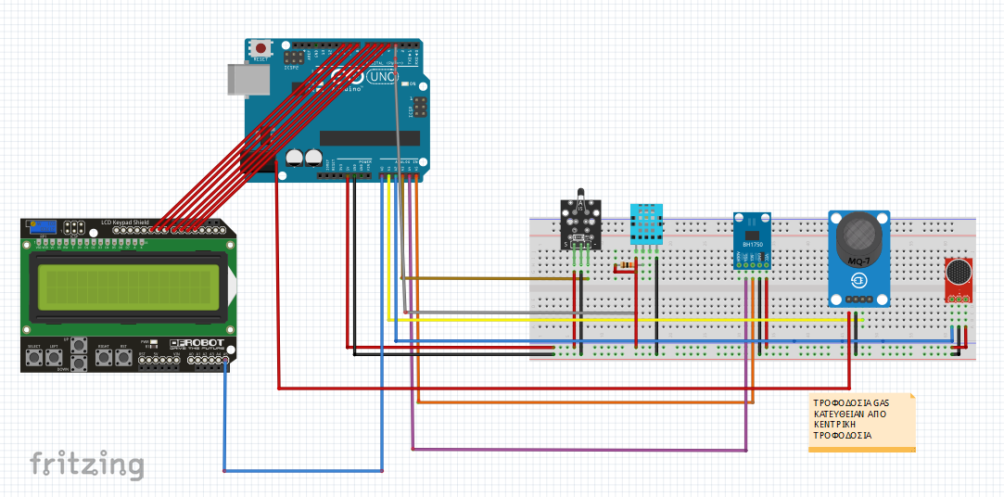
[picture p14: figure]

Εικόνα 1:το τελικό κύκλωμα

Ο αλγόριθμος που αποφασίζει τη βαθμολογία

Είχαμε σκεφτεί στην αρχή να αποθηκεύουμε τις τιμές των μετρήσεων σε έναν πίνακα και να βγάζουμε τον μέσο όρο. Αυτή η προσέγγιση δεν ήταν εφικτή διότι

1) ο πίνακας θα έπρεπε να είναι πολύ μεγάλος.

2)Ακόμα κι αν μπορούσαμε να είχαμε χιλιάδες τιμές και να βγάζουμε τον μέσο όρο θα ήταν λάθος. Για να το εξηγήσουμε αυτό θα σας παρουσιάσουμε ένα παράδειγμα του αισθητήρα θερμοκρασίας.

Έστω ότι στην πρώτη περίπτωση είχαμε πάρει από μία τάξη τις εξής 10 μετρήσεις:

17, 23, 17, 23, 17, 23, 17, 23, 17, 23 (oC) = Ο μέσος όρος θα ήταν 20 oC.

Ενώ στη δεύτερη περίπτωση είχαμε πάρει τις εξής 10 μετρήσεις:

20, 20, 20, 20, 20, 20, 20, 20, 20, 20 (oC) = Ο μέσος όρος προκύπτει πάλι 20 oC.

Δεν είναι σωστός λοιπόν ο μέσος όρος γιατί δεν δείχνει το ανεβοκατέβασμα της πρώτης τάξης και τελικά την δείχνει ίδια με τη δεύτερη ενώ δεν είναι.

Για να λύσουμε το παραπάνω πρόβλημα, σε κάθε αισθητήρα έχουμε έναν πίνακα κατανομής (distrib) πέντε θέσεων. Κάθε φορά που παίρνουμε μέτρηση από τον αισθητήρα αυξάνεται κατά ένα, η μία από τις πέντε θέσεις του αντίστοιχου πίνακα κατανομής. Επίσης για κάθε αισθητήρα έχουμε έναν πίνακα, τα στοιχεία του οποίου εκφράζουν τα όρια της κάθε ζώνης (limits). Υπάρχουν τρεις ζώνες: η green, η yellow και η red. Η green εκφράζει τις αποδεκτές μετρήσεις, η yellow τις μεσαίες και η red τις μη αποδεκτές. Η green είναι το μεσαίο στοιχείο του πίνακα (distrib[2]), η yellow είναι τα distrib[1] και distrib[3] ενώ η red τα distrib[0] και distrib[4].

Κάθε φορά που καλείται η συνάρτηση υπολογισμού της ποιότητας της τάξης, βρίσκουμε το ποσοστό των καλών, των μέτριων και των κακών μετρήσεων. Για να το κάνουμε αυτό αρχικά προσθέτουμε τα στοιχεία του πίνακα και αποθηκεύουμε το αποτέλεσμα στην μεταβλητή SUM. Έπειτα διαιρούμε τις καλές μετρήσεις (distrib[2]) με το SUM,διαιρούμε τις μέτριες μετρήσεις (distrib[1]+distrib[3]) με το SUM και τέλος τις κακές μετρήσεις (distrib[0]+distrib[4]) πάλι με το SUM.

Για παράδειγμα παίρνουμε 3% κακές μετρήσεις, 27% μέτριες μετρήσεις και 70% άριστες. Τώρα έρχεται ένα άλλο πρόβλημα: Πως βαθμολογείται αυτή η τάξη μας μετά από όλες αυτές τις μετρήσεις μαζί; Κακή, μέτρια ή άριστη;

Πρέπει να αποφασίσουμε εάν το ποσοστό των άριστων μετρήσεων είναι αρκετά υψηλό και το ποσοστό των κακών και των μέτριων μετρήσεων είναι αρκετά χαμηλό. Σκεφτήκαμε το εξής. Αν πάνω από 5% είναι κακές μετρήσεις τότε το τελικό αποτέλεσμα είναι κακό. Δηλαδή αν σε μία ώρα ο θόρυβος είναι τεράστιος πάνω από τρία λεπτά, τότε όλη η ώρα βαθμολογείται κακή. Για να βγει μέτρια πρέπει να είναι 12 λεπτά μέτρια, αλλιώς (δηλαδή πάνω από 45 λεπτά) βγαίνει άριστη.

Για να το φτιάξουμε σε κώδικα συγκρίνουμε αρχικά το ποσοστό των κακών μετρήσεων με ένα ποσοστιαίο όριο που θέσαμε εμείς (5%). Έπειτα συγκρίνουμε το ποσοστό των μέτριων μετρήσεων με το 20%. Τέλος τις καλές μετρήσεις με το 75%. Παρακάτω παρουσιάζεται η συνάρτηση που χρησιμοποιούμε που διαβάζει έναν πίνακα κατανομών και επιστρέφει BAD ή MED ή OK!

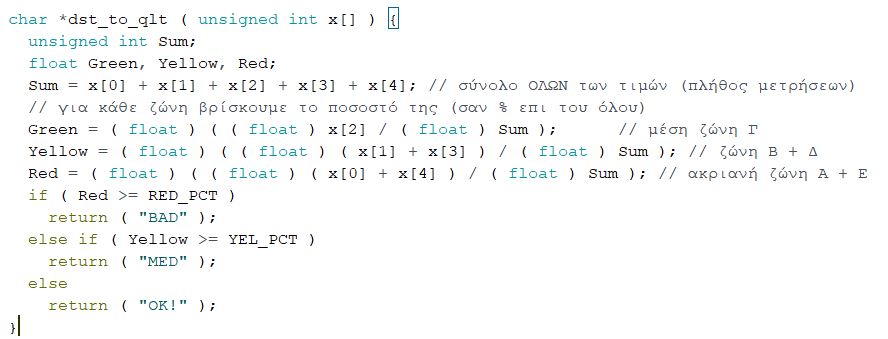
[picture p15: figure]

Εικόνα 2: H συνάρτηση dst_to_q1t

Όλα είναι παραμετρικά στο πρόγραμμά μας και εύκολα αλλάζουμε τα ποσοστά πχ. αλλάζουμε το #define RED_PCT 0.05 σε #define RED_PCT 0.10 για να κάνουμε να ανάβει κόκκινο αν έχουμε πάνω από 10% κακές μετρήσεις.

Τέλος για να βαθμολογήσουμε ΟΛΗ την τάξη, έχοντας 5 αισθητήρες κόκκινους, κίτρινους ή πράσινους ο καθένας διαφορετικός σκεφτήκαμε διάφορα, απλά και πολύπλοκα, και καταλήξαμε τελικά στο εξής απλό:

Αν δύο ή παραπάνω είναι κόκκινοι, τότε όλη η τάξη είναι κόκκινη, αλλιώς

αν τέσσερις ή παραπάνω είναι πράσινοι τότε όλη η τάξη είναι πράσινη, αλλιώς

ολη η τάξη είναι κίτρινη. Αυτό είναι εύκολο να το θυμόμαστε, εύκολο να το αλλάξουμε και μοιάζει τελικά σωστότερο από όλα τα άλλα που σκεφτήκαμε.

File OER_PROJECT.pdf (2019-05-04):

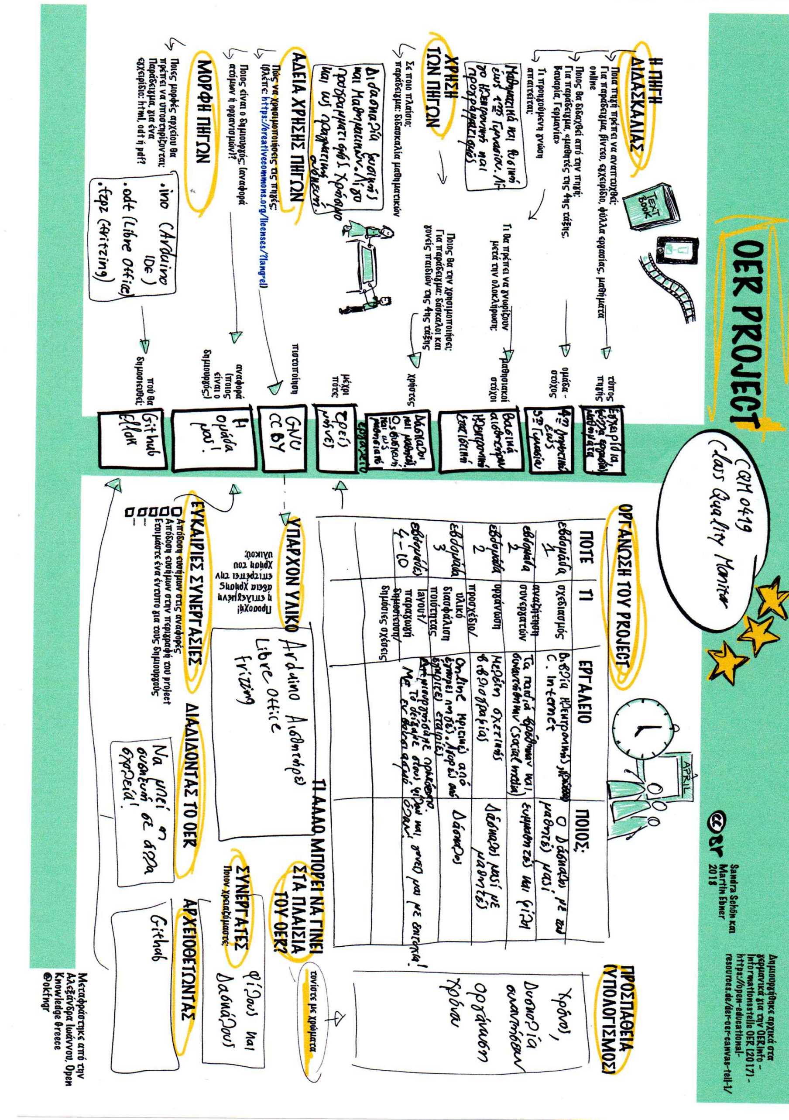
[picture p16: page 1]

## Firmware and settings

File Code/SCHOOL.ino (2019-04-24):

/* ΠΡΟΓΡΑΜΜΑ ΕΛΕΓΧΟΥ ΠΟΙΟΤΗΤΑΣ ΤΑΞΗΣ
   ΙΑΝΟΥΑΡΙΟΣ - ΑΠΡΙΛΙΟΣ 2019

   Ελέγχουμε διάφορες μετρήσεις και βαθμολογούμε ανάλογα
   Ο κάθε αισθητήρας δίνει πράσινο, κίτρινο, ή κόκκινο ανάλογα με προκαθορισμένα όρια
   ΟΛΟΙ οι αισθητήρες μαζί, δίνουν ένα βαθμό πράσινο, κίτρινο, ή κόκκινο

   Χρησιμοποιούμε τους παρακάτω αισθητήρες


   DHT11 - Temperature : παράδειγμα από samples τιμών 25,26,27
   DHT11 - Humidity :  samples 34,33,28
   MQ135 Air qlt : samples 250,270,290
   BH1750 Light Sensor : samples 600,700,800
   Sparkfun Electret microphone: samples 500-700
   KY-013 - Analog Temp: samples 25,26,27

  ΑΞΙΟΛΟΓΗΣΗ ΓΙΑ ΠΡΑΣΙΝΟ/ΚΙΤΡΙΝΟ/ΚΟΚΚΙΝΟ ΒΑΘΜΟ
  θέτουμε *εμείς* τα παρακάτω επίπεδα αξιολόγησης

  -   3 λεπτά ανοχή στην μία ώρα για τις κακές μετρήσεις (κόκκινο) = 5% του χρόνου.
  -  12 λεπτά ανοχή στην μία ώρα για τις μέτριες μετρήσεις (κίτρινο) = 20% του χρόνου.
  -  45 λεπτά ανοχή στην μία ώρα για της καλές (πράσινο) = 75% του χρόνου.
  ΩΡΑ ΕΝΝΟΕΙΤΑΙ 60 ΛΕΠΤΑ ΚΑΙ ΟΧΙ 45


  Σε κάθε αισθητήρα ορίζουμε 5 ζώνες τιμών
   -- μία πράσινη
   -- δύο κίτρινες
   -- δύο κόκκινες. Περισσότερα στον κώδικα
*/

#include <LiquidCrystal.h>      // lcd screen
#include "globals.h"            // παράμετροι που χρησιμοποιούμε σε όλο το πρόγραμμα (globals)
LiquidCrystal lcd ( 8, 9, 4, 5, 6, 7 ); // select the pins used on the LCD panel


int lcd_button;                 //  which lcd button was presed
int which_button;               //ποιό κουμπί πατήθηκε από την lcd

float Hum, Temp1, Temp2;        //  humidity, temperature of DHT_11 and KY013 live measurements
uint16_t Light;                 //  light indensity  BH1750 live measurement
int Gas;                        //  CO2
unsigned int Sound;             //  sound live measurement

int i = 0;                    //η μεταβλητή που χρησιμοποιούμε σε ένα loop

char line0[16], line1[16];    // οι δύο σειρές της οθόνης

unsigned long Millis_Now, Millis_Lap_Disp, Millis_Lap_Read; //μετρητές χρόνου.Θέλουμε να αξιολογούμε την ποιότητα των μετρήσεων περιοδικά

void read_from_all_sensors() {
  //Τώρα παίρνουμε τις live μετρήσεις

  Sound = read_sound_100();
  Light = read_LIGHT();
  // Light = constrain ( Light, Limits_Light[0], Limits_Light[5] );
  Gas = read_gas();
  Temp1 = read_DHT11_temp();
  Hum = read_DHT11_hum();
  Temp2 = read_Analog_Temp();
  // σε κάθε loop ενημερώνουμε τους πίνακες κατανομής
  for ( i = 0; i <= 5; i++ ) {
    if ( Light > ( Limits_Light[i] ) && ( Light <= ( Limits_Light[i + 1] ) ) )
      dst_Light[i] = dst_Light[i] + 1;
    if ( Temp2 > ( Limits_Temp[i] ) && ( Temp2 <= ( Limits_Temp[i + 1] ) ) )
      dst_Temp[i] = dst_Temp[i] + 1;
    if ( Hum > ( Limits_DH11_hum[i] ) && ( Hum <= ( Limits_DH11_hum[i + 1] ) ) )
      dst_DH11_hum[i] = dst_DH11_hum[i] + 1;
    if ( Temp1 > ( Limits_DH11_Temp[i] ) && ( Temp1 <= ( Limits_DH11_Temp[i + 1] ) ) )
      dst_DH11_Temp[i] = dst_DH11_Temp[i] + 1;
    if ( Gas > ( Limits_MQ7[i] ) && ( Gas <= ( Limits_MQ7[i + 1] ) ) )
      dst_MQ7[i] = dst_MQ7[i] + 1;
    if ( Sound > ( Limits_Sound[i] ) && ( Sound <= ( Limits_Sound[i + 1] ) ) )
      dst_Sound[i] = dst_Sound[i] + 1;
  }
}

void show_on_lcd_all_results() {
  int num_of_reds = 0, num_of_yellows = 0, num_of_greens = 0, j;
  char * result = "!";
  sprintf (line1, "%s%s%s%s%s%s", dst_to_qlt(dst_Sound), dst_to_qlt(dst_Light), dst_to_qlt(dst_MQ7), dst_to_qlt(dst_Temp), dst_to_qlt(dst_DH11_hum), result);
  for (j = 0; j <= 12; j += 3) {
    if (line1[j] == 'B') num_of_reds++;   // BAD
    if (line1[j] == 'M') num_of_yellows++; // MED
    if (line1[j] == 'O') num_of_greens++; // OK!
  }


  if (num_of_reds >= 2)
  { result = "R";
    RGB_color(255, 0, 0); // Red
  } else if (num_of_greens >= 4) {
    RGB_color(0, 255, 0); // Green
    result = "G";
  }
  else {
    RGB_color(255, 255, 255); // White for Yellow
    result = "Y";
  }

  lcd.setCursor ( 0, 0 );
  lcd.print ( "SndLigGasTmpHumG");
  lcd.setCursor ( 0, 1 );

  sprintf (line1, "%s%s%s%s%s%s", dst_to_qlt(dst_Sound), dst_to_qlt(dst_Light), dst_to_qlt(dst_MQ7), dst_to_qlt(dst_Temp), dst_to_qlt(dst_DH11_hum), result);

  lcd.print ( line1 );

} // end show_on_lcd_all_results

void setup() {
  if (enable_print == 1)   // debugging purposes
    Serial.begin(9600);

  //initialise sensors
  setup_lcd();
  lcd.clear();
  lcd.setCursor ( 0, 0 );
  lcd.print ("CLASS QUALITY v1" );
  lcd.setCursor ( 0, 1 );
  lcd.print ("SENSORS CHECK " );
  pinMode(red_light_pin, OUTPUT);
  pinMode(green_light_pin, OUTPUT);
  pinMode(blue_light_pin, OUTPUT);

  setup_Analog_Temp();
  setup_DHT11();
  setup_gas();
  setup_Sound_Sensor();
  setup_LIGHT();
  Millis_Lap_Disp = millis();
  Millis_Lap_Read = millis();

  lcd.print ("OK" );
  delay(2000);
  lcd.clear();
} //  end setup

void loop() {
  Millis_Now = millis();
  // περιοδικά (κάθε DISPLAY_EVERY msecs) αξιολογούμε και δείχνουμε ΟΛΑ τα αποτελέσματα των κατανομών

  if ( ( Millis_Now - Millis_Lap_Disp ) > DISPLAY_EVERY ) {
    show_on_lcd_all_results();
    Millis_Lap_Disp = Millis_Now;
    delay(7000);
  } // end display results

  // περιοδικά (κάθε READ_EVERY msecs) διαβάζουμε από ολους τους αισθητήρες
  if ( ( Millis_Now - Millis_Lap_Read ) > READ_EVERY ) {
    read_from_all_sensors();
    Millis_Lap_Read = Millis_Now;
  }

  //
  which_button = read_LCD_buttons();
  switch ( which_button ) {           // depending on which button was pushed, we perform an action
    case buttonSELECT: {
        lcd_button = 0;
        break;
      }
    case buttonLEFT: {
        lcd_button = 1;
        break;
      }
    case buttonDOWN: {
        lcd_button = 2;
        break;
      }
    case buttonRIGHT: {
        lcd_button = 4;
        break;
      }
    case buttonUP: {
        lcd_button = 3;
        break;
      }
  } // end switch button pressed

  if ( lcd_button == 0 )
    show_on_lcd_dst ( "TEM ", dst_Temp, ( int ) Temp1 );
  if ( lcd_button == 1 )
    show_on_lcd_dst ( "LGT ", dst_Light, ( int ) Light );
  if ( lcd_button == 2 )
    show_on_lcd_dst ( "HUM ", dst_DH11_hum, ( int ) Hum );
  if ( lcd_button == 3 )
    show_on_lcd_dst ( "GAS ", dst_MQ7, ( int ) Gas );
  if ( lcd_button == 4 )
    show_on_lcd_dst ( "SND ", dst_Sound, ( int ) Sound );
}


// display on LCD sensor name, distribution of sensor, live reading
void show_on_lcd_dst ( char sens[], unsigned int dOfS[], int live ) {

  sprintf ( line0, "%3d%3d%4d%3d%3d", dOfS[0], dOfS[1], dOfS[2], dOfS[3], dOfS[4] );
  lcd.setCursor ( 0, 0 );
  lcd.print ( line0 );
  sprintf ( line1, "%s<%5d> %s ", sens, live, dst_to_qlt ( dOfS ) );
  lcd.setCursor ( 0, 1 );
  lcd.print ( line1 );
}

// dst_to_qlt (x)
// input : ένα πίνακα κατανομών x, και επιστρέφει
// output: string BAD, MED, OK! ανάλογα το πλήθος και την κατανομή ανά εύρος

char *dst_to_qlt ( unsigned int x[] ) {
  unsigned int Sum;
  float Green, Yellow, Red;
  Sum = x[0] + x[1] + x[2] + x[3] + x[4]; // σύνολο ΟΛΩΝ των τιμών (πλήθος μετρήσεων)
  // για κάθε ζώνη βρίσκουμε το ποσοστό της (σαν % επι του όλου)
  Green = ( float ) ( ( float ) x[2] / ( float ) Sum );      // μέση ζώνη Γ
  Yellow = ( float ) ( ( float ) ( x[1] + x[3] ) / ( float ) Sum ); // ζώνη Β + Δ
  Red = ( float ) ( ( float ) ( x[0] + x[4] ) / ( float ) Sum ); // ακριανή ζώνη Α + Ε
  if ( Red >= RED_PCT )
    return ( "BAD" );
  else if ( Yellow >= YEL_PCT )
    return ( "MED" );
  else
    return ( "OK!" );
}

// set RGB led color
void RGB_color(int red_light_value, int green_light_value, int blue_light_value)
{
  analogWrite(red_light_pin, red_light_value);
  analogWrite(green_light_pin, green_light_value);
  analogWrite(blue_light_pin, blue_light_value);
}

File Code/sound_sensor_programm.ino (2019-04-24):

int SOUND_NOW;

void setup_Sound_Sensor() {
  // put your setup code here, to run once:
  pinMode ( A2, INPUT );
  //Serial.begin(9600);
}

int read_Sound_Sensor() {
  SOUND_NOW = analogRead ( A2 );
  //Serial.print("Sound voltage ");
  if ( enable_print == 1 ) {
    //Serial.println(SOUND_NOW);
  }
  return ( SOUND_NOW );
}

unsigned int read_sound_100() {
  int abc;
  unsigned long int ab;
  ab = 0;
  for ( i = 0; i <= 100; i++ ) {
    Sound = read_Sound_Sensor();
    if ( Sound > 500 ) {
      abc = Sound - 500;
    } else {
      abc = 500 - Sound;
    }
    ab = abc + ab;
  }
  ab = ab / 100;
  if ( enable_print == 1 ) {
    Serial.print ( " entash 100 deigmatwn:" );
    Serial.println ( ab );
  }
  return ( ab );
}
